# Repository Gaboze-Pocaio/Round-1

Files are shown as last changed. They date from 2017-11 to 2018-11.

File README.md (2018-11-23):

-----

# Where Can I Buy One
> You can purchase an assembled Gaboze Pocaio on [Tindie](https://www.tindie.com/products/thirtytwoteeth/gaboze-pocaio-game-boy-pocket-all-in-one/)

[](https://www.tindie.com/products/thirtytwoteeth/gaboze-pocaio-game-boy-pocket-all-in-one/)

-----

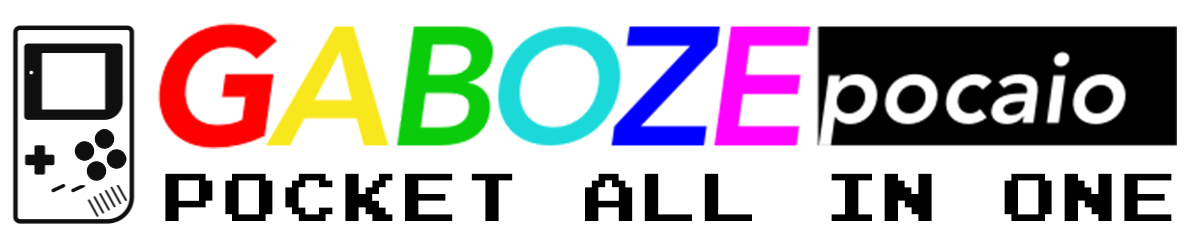
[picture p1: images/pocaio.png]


## Introduction

### Gaboze Pocaio - Pocket All In One
Raspberry Pi Zero based arcade in you pocket, and in your Gameboy Pocket

### Features:

* 2.4" TFT LCD
* Gameboy button layout interface
* Raspberry Pi Zero
* Battery Charger (TP4056 Module)
* Headphone Jack (LM4857)
* Speaker capability (LM4857)

### Platforms:

The boards have been tested with the following platforms:

- [x] [Emulation Station](http://www.emulationstation.org/)
- [x] [Lakka](http://www.lakka.tv/)
### [Lakka for Gaboze Pocaio](https://github.com/32teeth/Lakka-For-Gaboze-Pocaio)
| Out Now | Build Your Own | Out Soon |
|:--:|:--:|:--:|
|  | | |
| *Gaboze Pocaio* | *Gaboze Pocaio Plus* | *Gaboze Pocaio ???* |

- [x] [RetroPie](https://retropie.org.uk/)

## DIY
> Building this yourself? Read the [Wiki](https://github.com/32teeth/GabozePocaio-Round1/wiki/)
* [Preperation](https://github.com/32teeth/GabozePocaio-Round1/wiki/DIY---Preperation)
* [Sound](https://github.com/32teeth/GabozePocaio-Round1/wiki/DIY---Sound-Components)
* [Display](https://github.com/32teeth/GabozePocaio-Round1/wiki/DIY---TFT-Display)

## Details
> The source files have been officially released. Check out the [Files](https://github.com/32teeth/GabozePocaio-Round1/tree/master/eagle/Release) and build away

| Top | Bottom |Money Shot |
| --- | --- |--- |
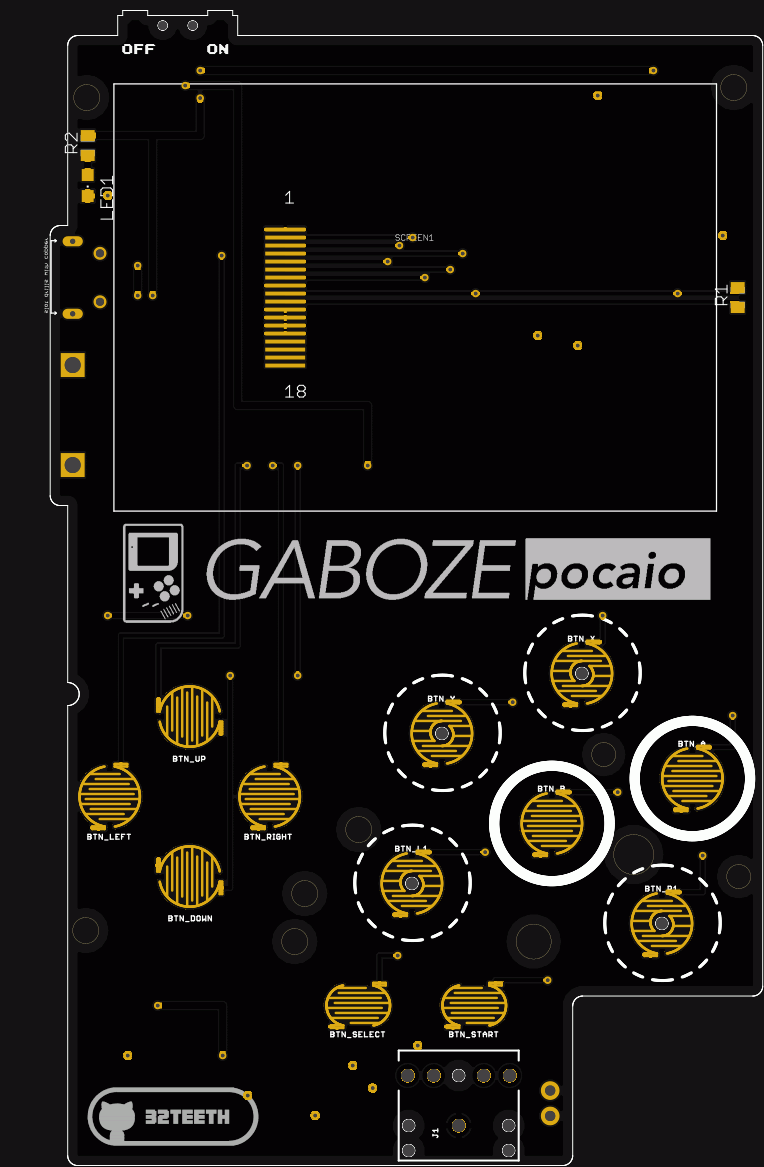
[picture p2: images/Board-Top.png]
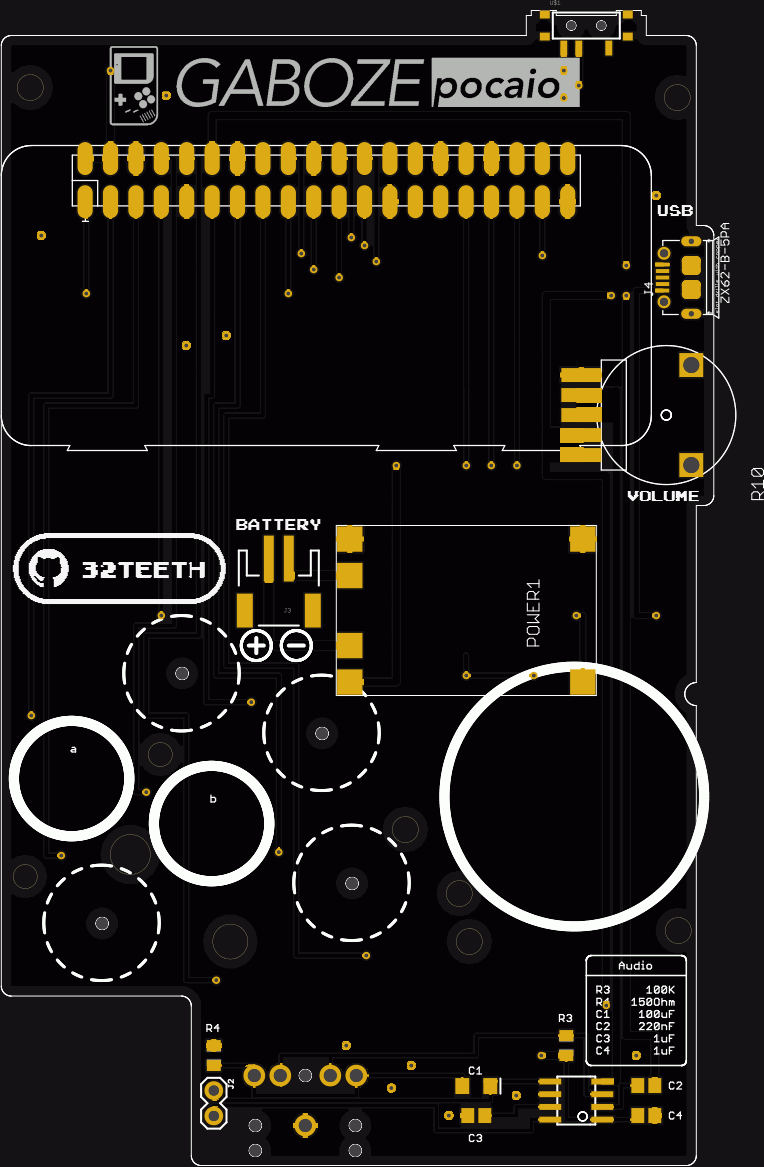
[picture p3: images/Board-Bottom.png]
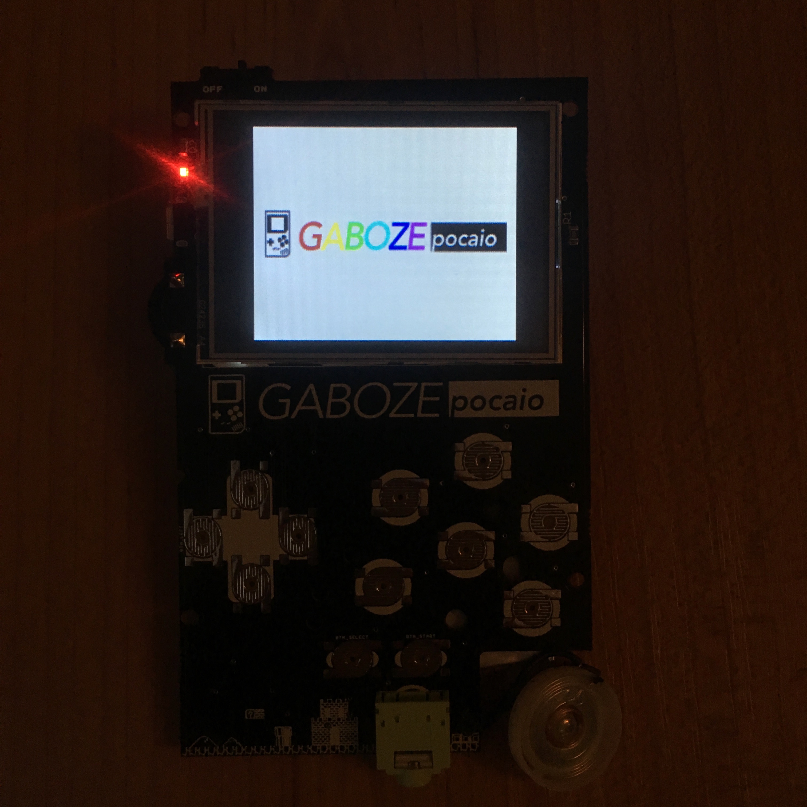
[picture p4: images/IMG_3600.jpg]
|  |  |  |

## Plus Edition
> This is a 2.6" TFT version of the Gaboze Pocaio. The Gerber Files are in the [Plus](https://github.com/32teeth/GabozePocaio-Round1/tree/master/gerber/Plus) folder

| Top | Bottom |Prototype Shot |
| --- | --- |--- |
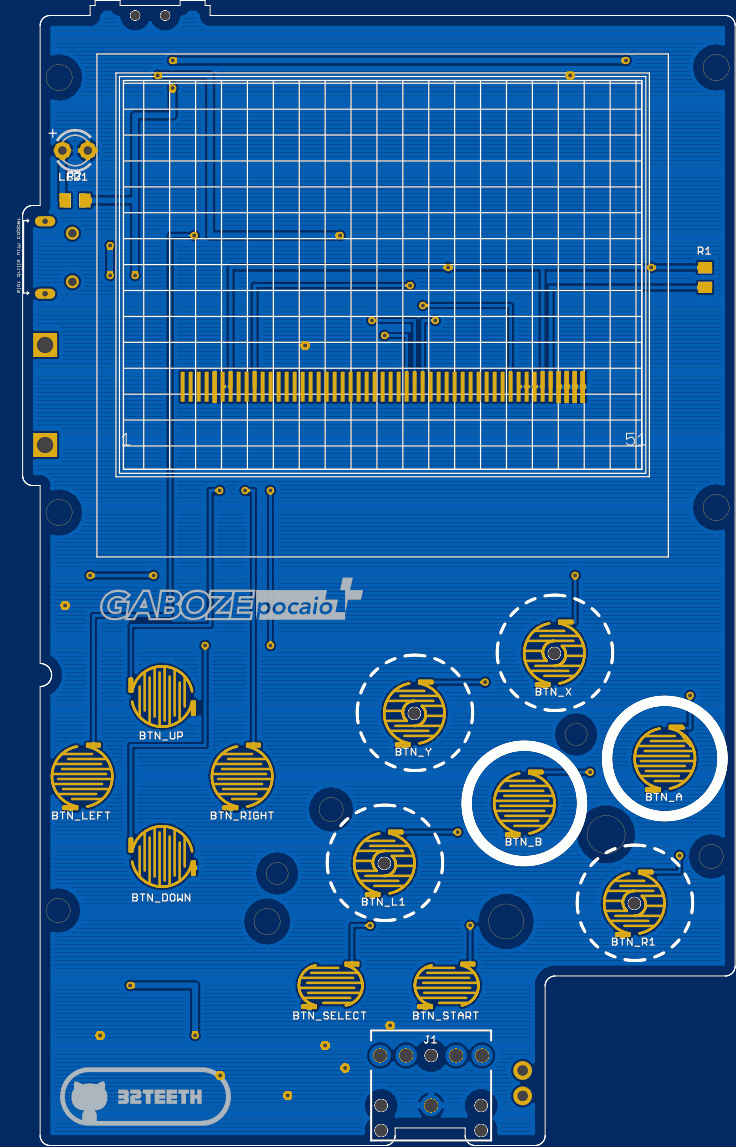
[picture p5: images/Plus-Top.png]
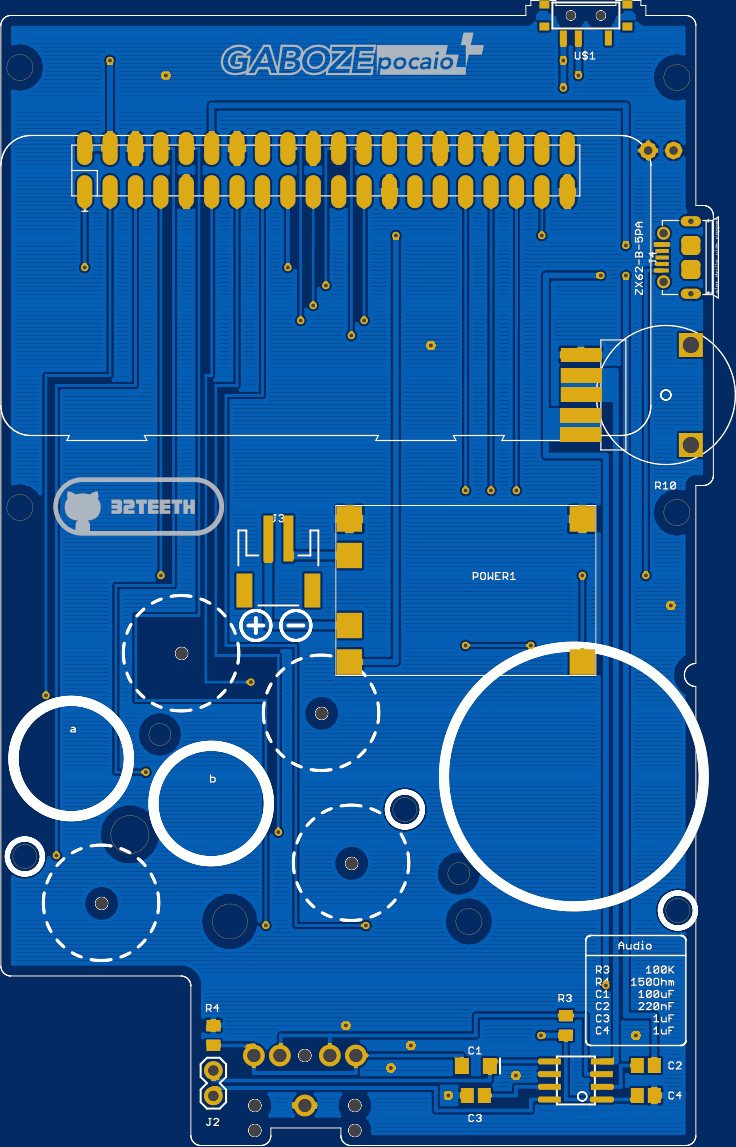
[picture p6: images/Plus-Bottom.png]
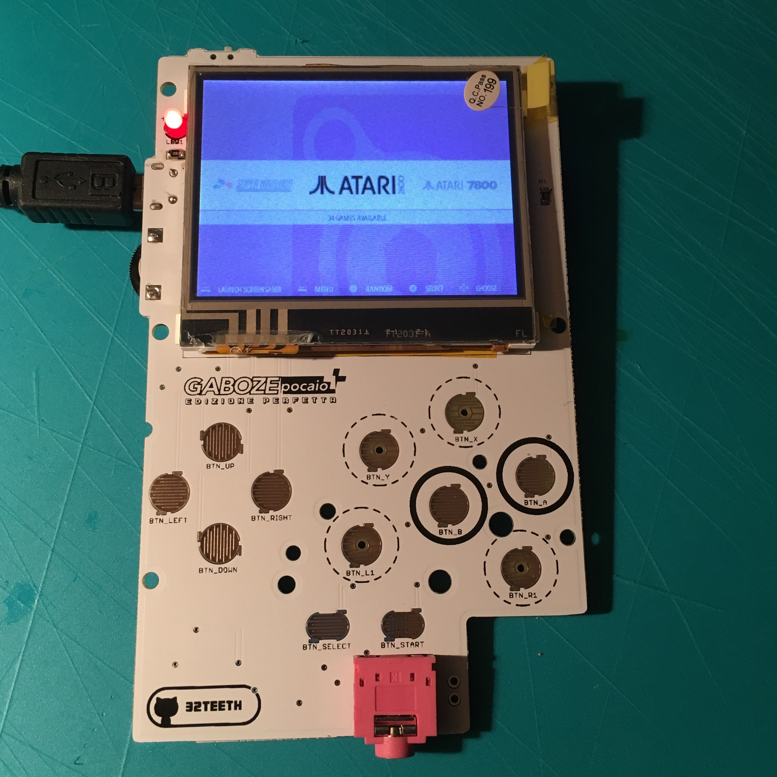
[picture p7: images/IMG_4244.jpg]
|  |  | |

| Overview | Front PCB | Back PCB | Screen | Layout | OSH |
| --- | --- | --- | --- | --- | --- |
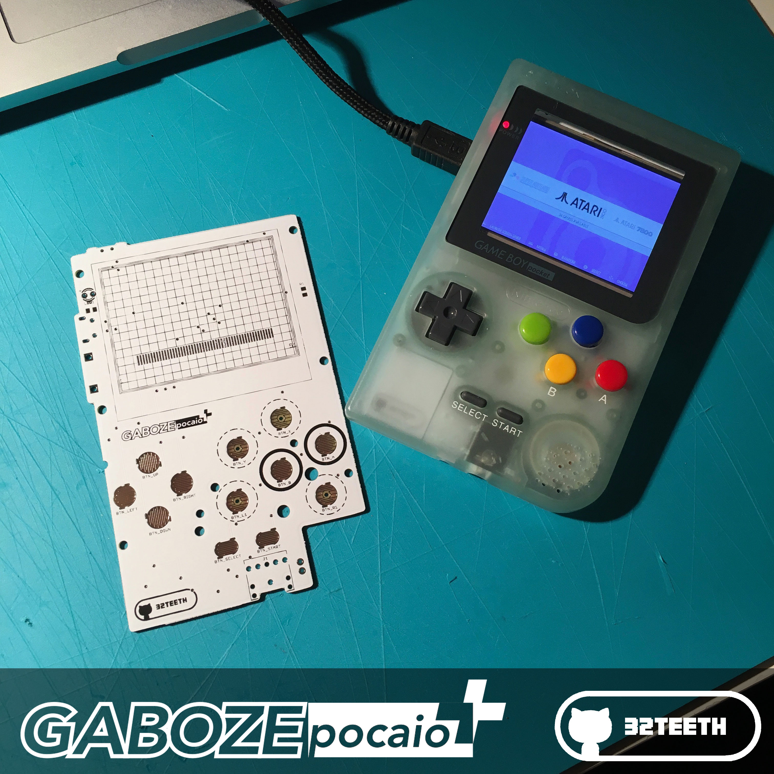
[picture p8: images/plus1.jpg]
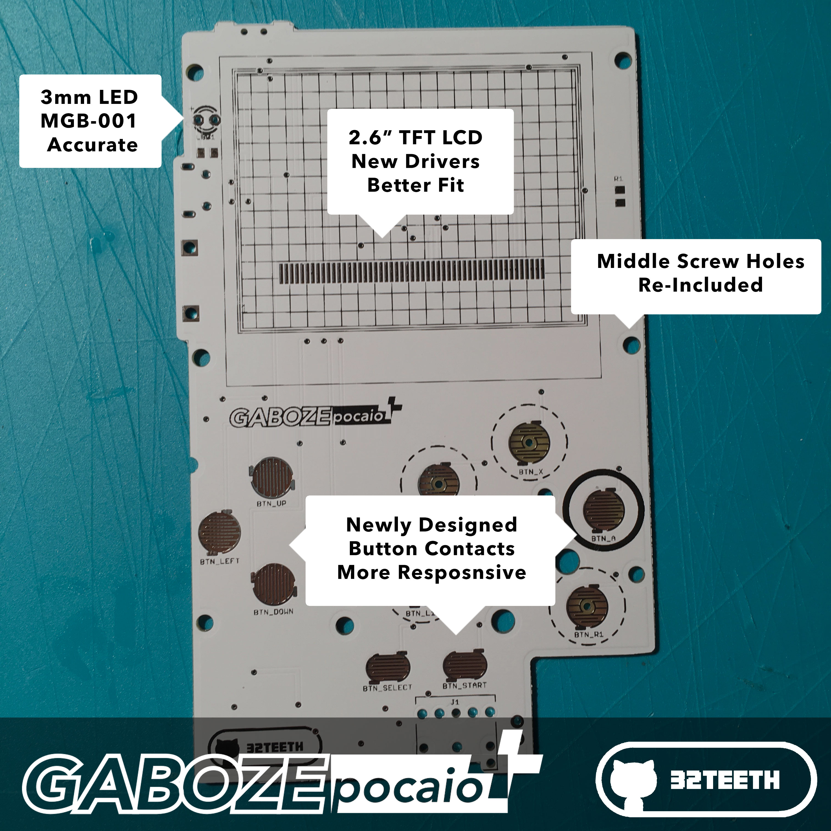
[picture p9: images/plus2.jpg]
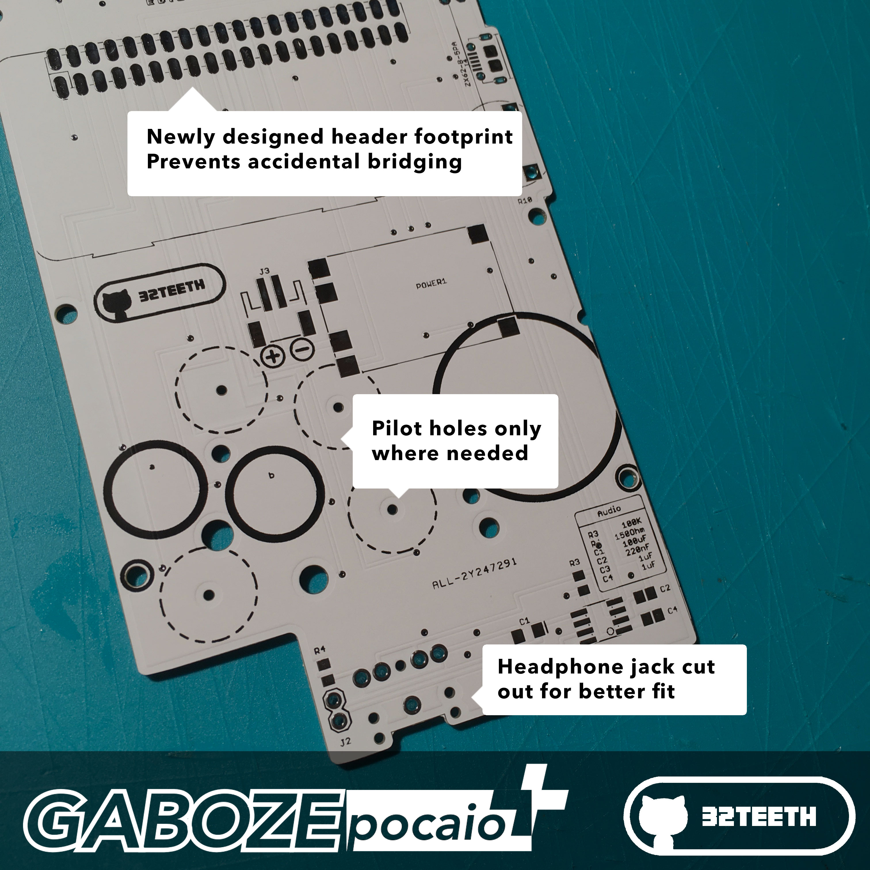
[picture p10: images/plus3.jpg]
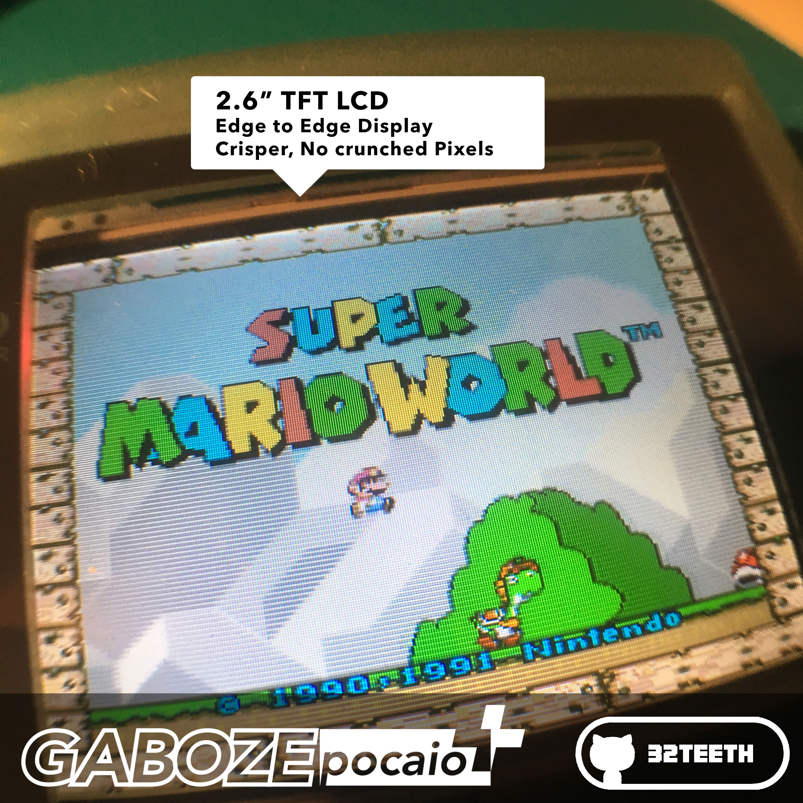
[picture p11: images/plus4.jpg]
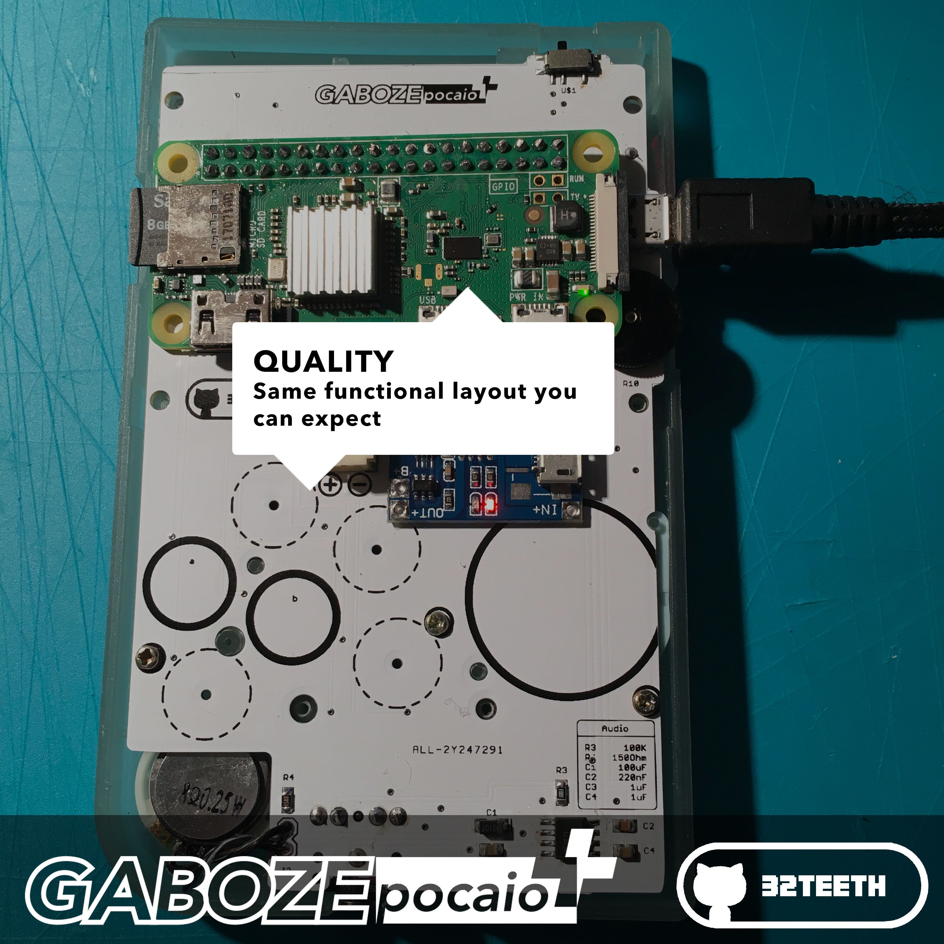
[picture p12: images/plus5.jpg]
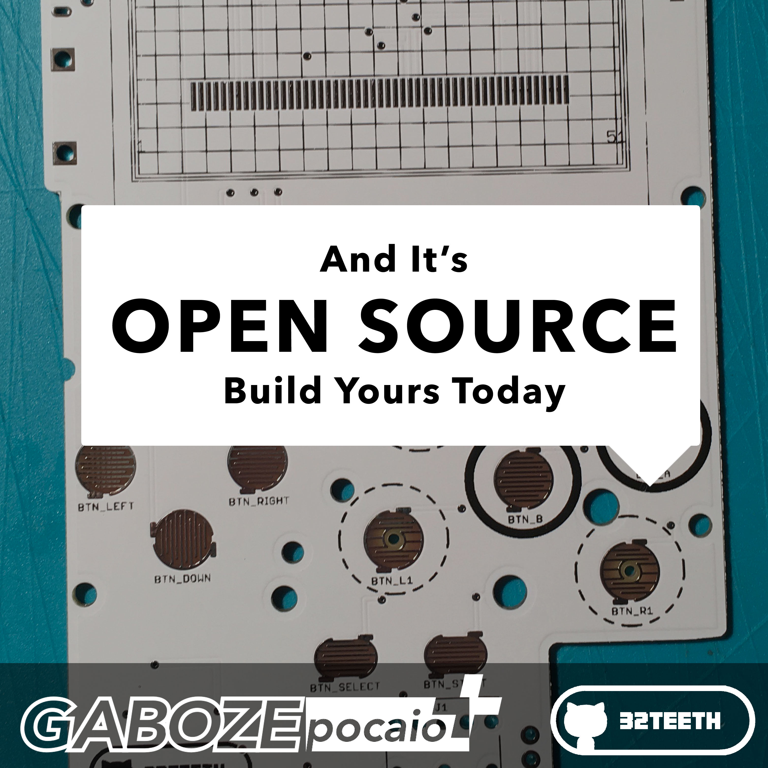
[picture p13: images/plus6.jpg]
|  |  |  |  |  |  |

## Extensions
> So you want to add your own components?

Check out the Gaboze Pocaio Extension Boards
These are available in the [gerber](https://github.com/32teeth/GabozePocaio-Round1/tree/master/gerber) folder

### Auxiliary Board

**Features **

* Power Indicator LED
* Volume Thumbwheel Potentiometer
* Power Input Pins
* Power + Potentiometer Output Pins

|Top|Bottom|Physical|
|-----|-----|-----|
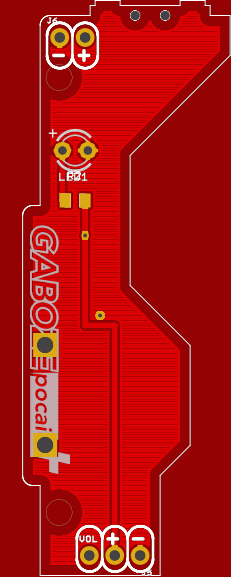
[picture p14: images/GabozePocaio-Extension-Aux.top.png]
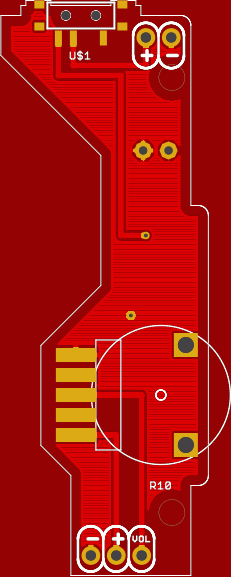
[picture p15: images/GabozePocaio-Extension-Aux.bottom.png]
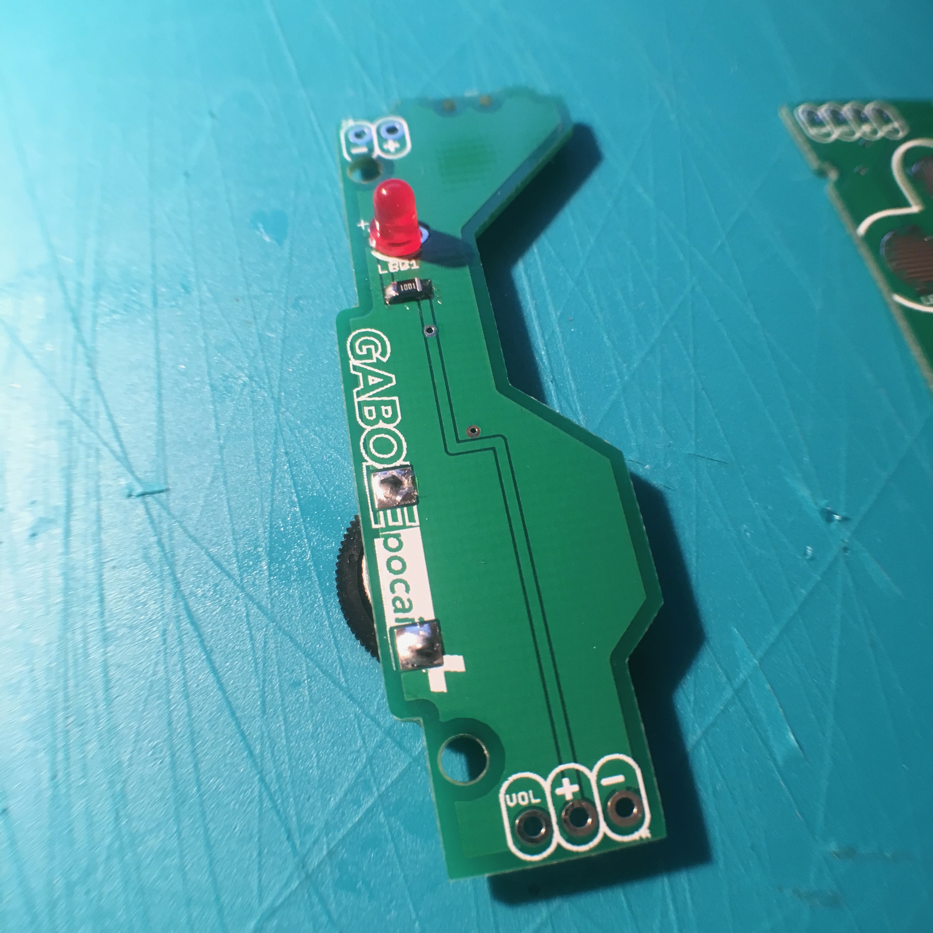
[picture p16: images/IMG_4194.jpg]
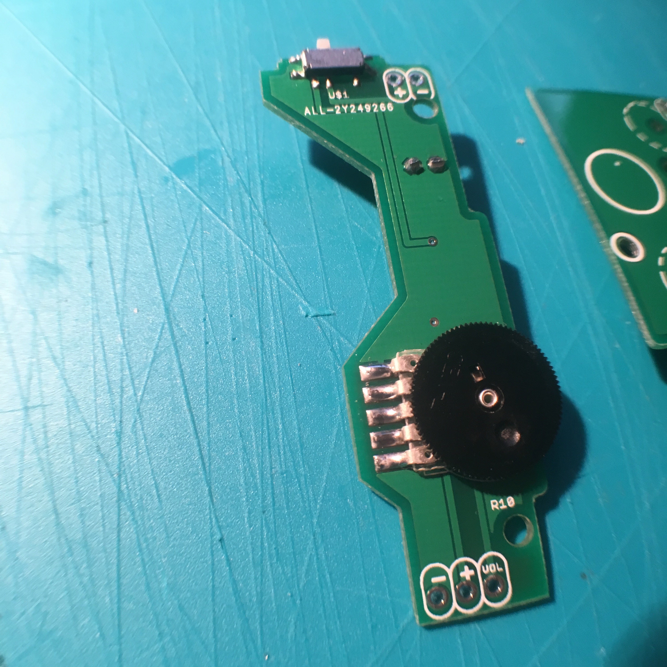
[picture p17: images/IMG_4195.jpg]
||||

[gerber](https://github.com/32teeth/GabozePocaio-Round1/tree/master/gerber/GabozePocaio-Extension-Aux)

### Button + Audio Board

**Features **

* LM4875 Audio Amp
* Headphone Jack
* 4/8 Ohm Speaker Output
* Power + PWM + Potentiometer Input Pins
* Button Pad Output Pins

|Top|Bottom|Physical|
|-----|-----|-----|
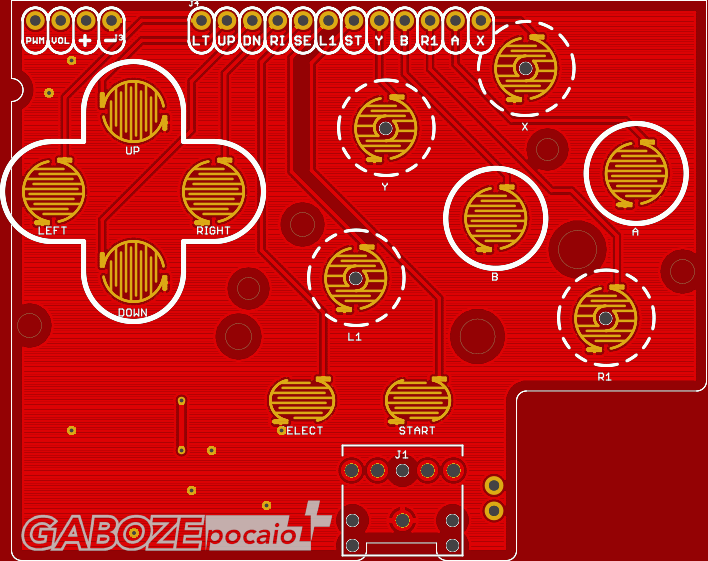
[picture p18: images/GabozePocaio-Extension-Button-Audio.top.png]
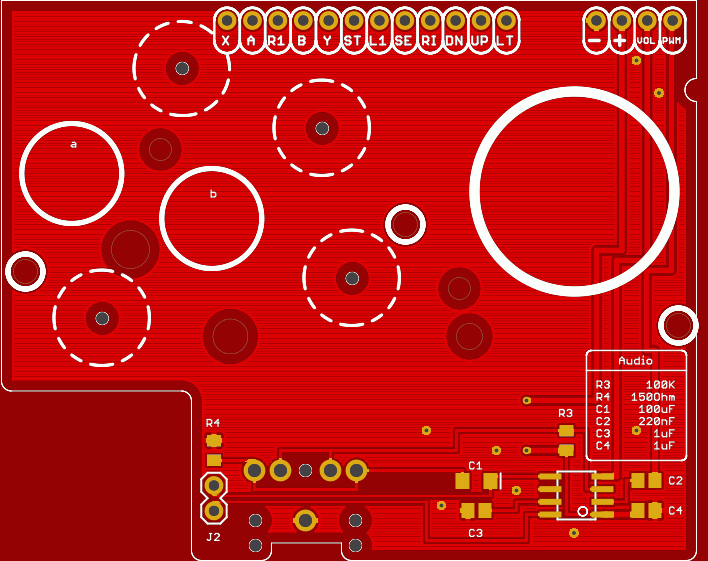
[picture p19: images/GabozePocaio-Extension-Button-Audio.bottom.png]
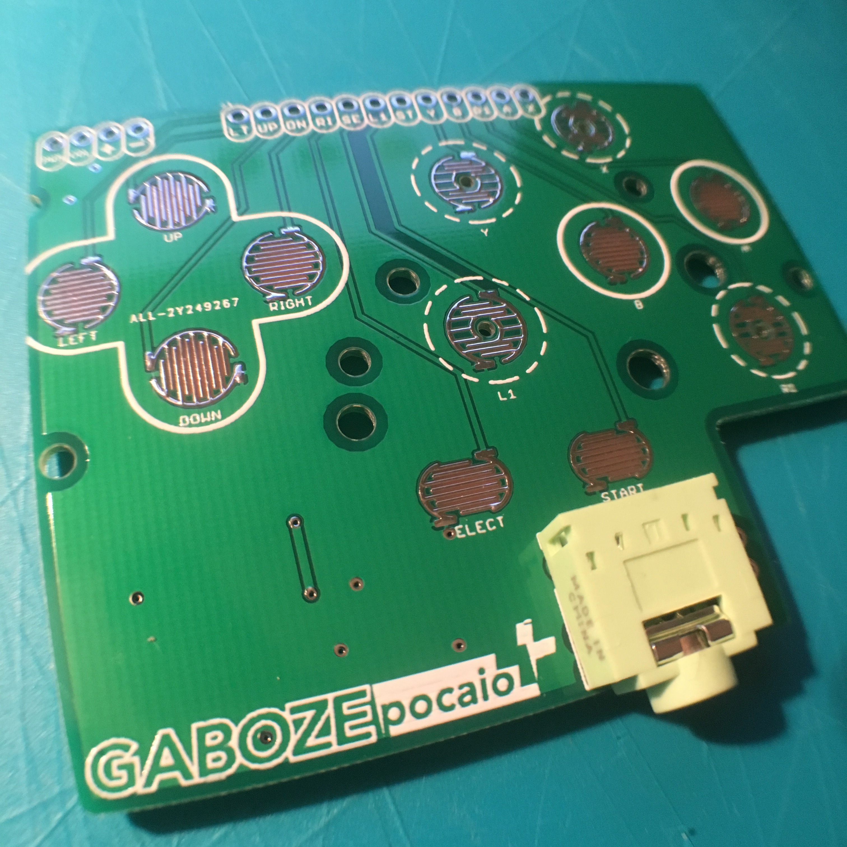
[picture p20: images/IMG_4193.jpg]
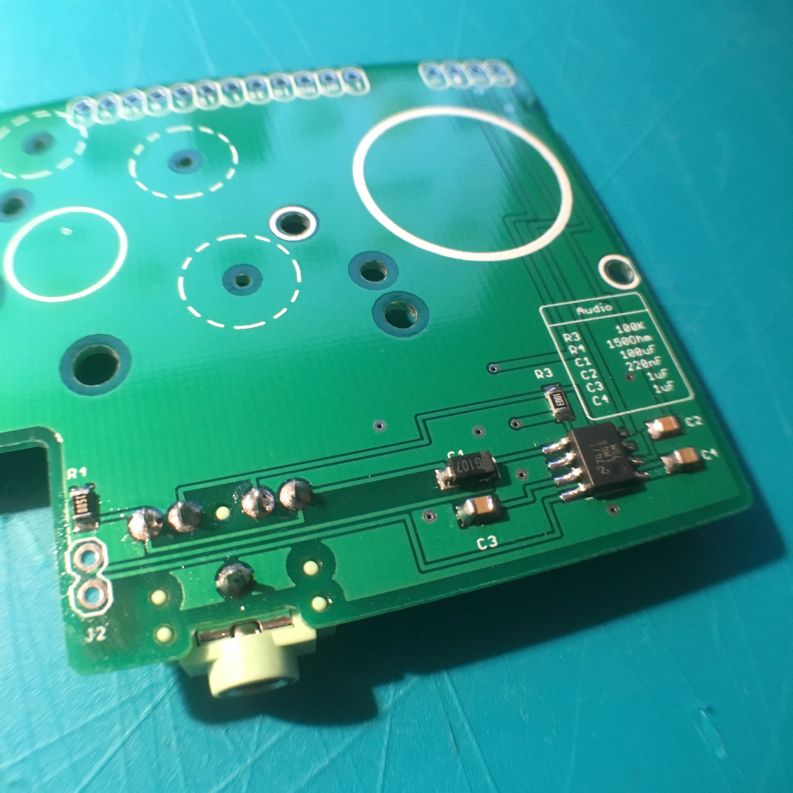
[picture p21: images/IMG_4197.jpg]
||||

[gerber](https://github.com/32teeth/GabozePocaio-Round1/tree/master/gerber/GabozePocaio-Extension-Button-Audio)

## Upgrade to 2.6"
> So you want to upgrade your screen size?

Here's the perfect daughter board solution
These are available in the [gerber](https://github.com/32teeth/GabozePocaio-Round1/tree/master/gerber) folder

**Features **

* Upgrade your display to a 2.6"

**Caviat**

* You WILL NEED to update your Raspberry Pi image with the ILI9342 driver
* If you choose to get a PCB made, make sure it's 0.6mm thickness (optimal is 0.4mm but it will be expensive)

|Top|Bottom|Physical|
|-----|-----|-----|
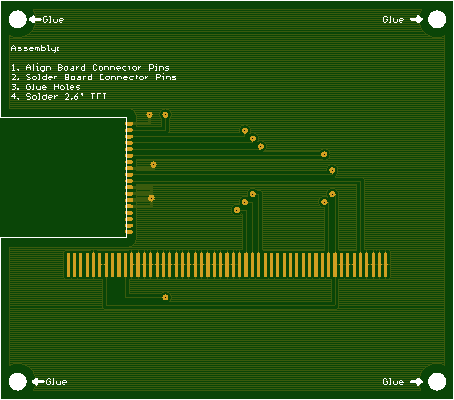
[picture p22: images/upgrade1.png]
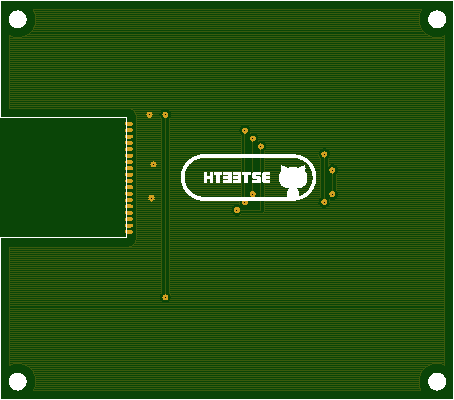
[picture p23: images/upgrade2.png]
|||NO IMAGE|

[source](https://github.com/32teeth/GabozePocaio-Round1/tree/master/eagle/Upgrade)
[gerber](https://github.com/32teeth/GabozePocaio-Round1/tree/master/gerber/Upgrade)

## Cartridge Shell
> So you want to print your own cartridge battery holder

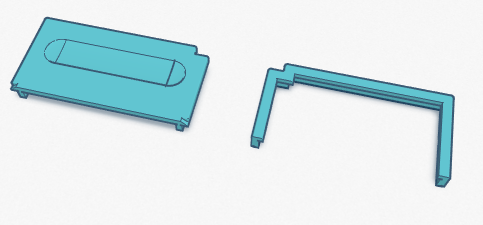
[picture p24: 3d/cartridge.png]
Cartridge Shell
|  |
|:--:|
| *[download stl](https://raw.githubusercontent.com/32teeth/GabozePocaio-Round1/master/3d/cartridge.stl)* |

# Buy me a Coffee
> This is a labor of love, and much time has been put in...  ...i could use a [coffee](https://www.paypal.me/32teeth/1usd) *(donuts are okay too)*

**Thank you for your support**

-----

## Seriously
> READ THE [WIKI](https://github.com/32teeth/GabozePocaio-Round1/wiki/)

-----

### Get In Touch

|    [](https://github.com/32teeth)[](https://www.instagram.com/thirtytwoteeth/)[](https://www.facebook.com/messages/t/32teeth)[](https://twitter.com/eugeneyevhen)[](https://www.youtube.com/user/32teeth/)[](https://ca.linkedin.com/in/32teeth)[](https://www.paypal.me/32teeth/5USD)  |
| ---- |
| Find me on the internet and lets chat |

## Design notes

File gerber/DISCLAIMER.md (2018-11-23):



-----

### Notice
> The gerber files are updated often, and are provided AS IS use
>
> They are provided for free, for educational purposes

* *see [LICENSE](../LICENSE.md) for more detail*

-----

### Combined Images

| Board-Top | Board-Bottom|
|:--:|:--:|
| *Board Top* |*Board Bottom*|

You can check the [EasyEDA Gerber Viewer](https://gerber-viewer.easyeda.com/showcase/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) before manufacturing

### Get In Touch

|    [](https://github.com/32teeth)[](https://www.instagram.com/thirtytwoteeth/)[](https://www.facebook.com/messages/t/32teeth)[](https://twitter.com/eugeneyevhen)[](https://www.youtube.com/user/32teeth/)[](https://ca.linkedin.com/in/32teeth)[](https://www.paypal.me/32teeth/5USD)  |
| ---- |
| Find me on the internet and lets chat |

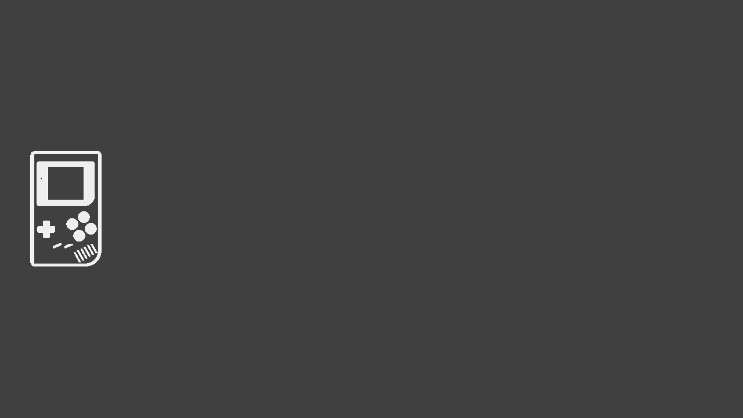
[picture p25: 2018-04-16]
images/animated.gif

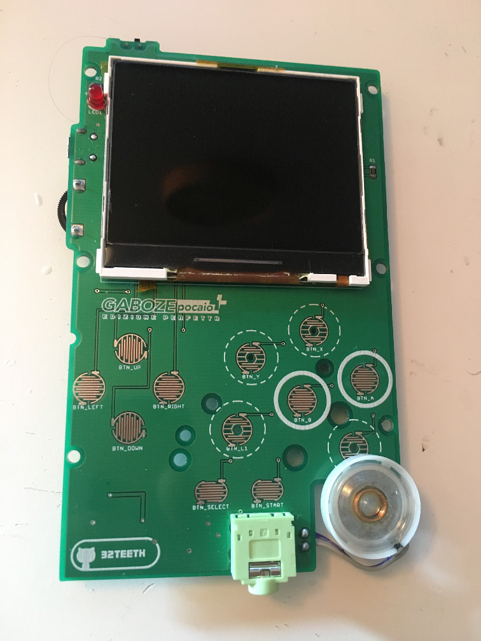
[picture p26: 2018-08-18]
images/plus.jpg

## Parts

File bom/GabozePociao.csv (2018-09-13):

Designator | Description | Manufacturer Part Number | Purchase Link | Quantity
POWER1 | Lithium Battery Charging Board | N/A | https://www.aliexpress.com/item/Free-Shipping-1PCS-5V-Micro-USB-1A-18650-Lithium-Battery-Charging-Board-With-Protection-Charger-Module/32476957358.html | 1
R2 | RES SMD 1.5K OHM 0.1% 1/4W 0805 | ERJ-PB6B1501V | https://www.digikey.ca/product-detail/en/panasonic-electronic-components/ERJ-PB6B1501V/P20612CT-ND/6214867 | 1
R1 | RES 3.9 OHM 1% 1/8W 0805 | RMCF0805FT3R90 | https://www.digikey.ca/product-detail/en/stackpole-electronics-inc/RMCF0805FT3R90/RMCF0805FT3R90CT-ND/2418397 | 1
R3 | RES 100K OHM 5% 1/4W 0805 | RPC0805JT100KCT | https://www.digikey.ca/product-detail/en/stackpole-electronics-inc/RPC0805JT100K/RPC0805JT100KCT-ND/5766007 | 1
C1 | CAP TANT 100UF 4V 20% 1206 | F930G107MAA | https://www.digikey.ca/product-detail/en/avx-corporation/F930G107MAA/478-8134-1-ND/4005954 | 1
R4 | RES 150 OHM 1% 1/4W 0805 | RNCP0805FTD150R | https://www.digikey.ca/product-detail/en/stackpole-electronics-inc/RNCP0805FTD150R/RNCP0805FTD150RCT-ND/2240550 | 1
C3,C4 | CAP CER 1UF 25V X7R 0805 | C0805C105K3RACTU | https://www.digikey.ca/product-detail/en/kemet/C0805C105K3RACTU/399-8004-1-ND/3471727 | 2
C2 | CAP CER 220PF 50V X7R 0805 | C0805C221M5RACTU | https://www.digikey.ca/product-detail/en/kemet/C0805C221M5RACTU/399-8039-1-ND/3471762 | 1
R10 | Replacement Volume Switch for Game boy | N/A | https://www.aliexpress.com/item/Replacement-Volume-Switch-for-Game-boy-for-GBA-GBC-Motherboard-Potentiomete-100pcs-lot/32830491244.html | 1
J3 | CONN HEADER PH SIDE 2POS 2MM SMD | S2B-PH-SM4-TB(LF)(SN | https://www.digikey.ca/product-detail/en/jst-sales-america-inc/S2B-PH-SM4-TB(LF)(SN)/455-1749-1-ND/926846 | 1
2.4TFT-ILI9341 | 2.4 inch SPI Serial LCD | N/A | https://www.aliexpress.com/item/2-4-inch-SPI-Serial-LCD-Without-Touch-ILI9341-4IO-Port-Can-Be-Driven-18-pin/32854563773.html | 1
U1 | IC AMP AUDIO PWR 1W MONO 8SOIC | LM4875MX-NOPB | https://www.digikey.ca/product-detail/en/texas-instruments/LM4875MX-NOPB/296-35282-1-ND/3738990 | 1
PI1 | CONN BERGSTIK II .100 in. DR SMD | 95157-440LF | https://www.digikey.ca/product-detail/en/amphenol-fci/95157-440LF/609-3124-ND/1824561 | 1
LED1 | LED RED CLEAR 0603 SMD | LTST-C191KRKT | https://www.digikey.ca/product-detail/en/lite-on-inc/LTST-C191KRKT/160-1447-1-ND/386836 | 1
X1 | CONN JACK STEREO 3.5MM R/A | CP1-3525NG-GR-ND | https://www.digikey.ca/product-detail/en/cui-inc/SJ1-3525NG-GR/CP1-3525NG-GR-ND/2295990 | 1
U$1 | SWITCH SLIDE SPDT 300MA 4V | MA12RTR | https://www.digikey.ca/product-detail/en/apem-inc/MA12RTR/679-1847-1-ND/1973774 | 1
J2 | SPEAKER 8OHM 250MW TOP PORT 80DB | PSR-20F08S-JQ | https://www.digikey.ca/product-detail/en/mallory-sonalert-products-inc/PSR-20F08S-JQ/458-1122-ND/2071438 | 1
J4 | CONN RCPT USB MICRO B SMD | ZX62D-B-5P8(30) | https://www.digikey.ca/product-detail/en/hirose-electric-co-ltd/ZX62D-B-5P8-30/H125272CT-ND/5994758 | 1

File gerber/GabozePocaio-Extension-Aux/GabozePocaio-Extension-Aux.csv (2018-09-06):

Designator | Description | Manufacturer Part Number | Purchase Link | Quantity
R2 | RES SMD 1.5K OHM 0.1% 1/4W 0805 | ERJ-PB6B1501V | https://www.digikey.ca/product-detail/en/panasonic-electronic-components/ERJ-PB6B1501V/P20612CT-ND/6214867 | 1
R10 | Replacement Volume Switch for Game boy | N/A | https://www.aliexpress.com/item/Replacement-Volume-Switch-for-Game-boy-for-GBA-GBC-Motherboard-Potentiomete-100pcs-lot/32830491244.html
LED1 | LED3MM RED (LED) | https://www.digikey.ca/product-detail/en/kingbright/WP710A10ID5V/754-1721-ND/3084187 | 1
U$1 | SWITCH SLIDE SPDT 300MA 4V | MA12RTR | https://www.digikey.ca/product-detail/en/apem-inc/MA12RTR/679-1847-1-ND/1973774 | 1
J5,J6 | NOT POPULATE | NOT POPULATED | 2

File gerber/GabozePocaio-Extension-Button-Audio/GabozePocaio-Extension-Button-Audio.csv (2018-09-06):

Designator | Description | Manufacturer Part Number | Purchase Link | Quantity
U1 | IC AMP AUDIO PWR 1W MONO 8SOIC | LM4875MX-NOPB | https://www.digikey.ca/product-detail/en/texas-instruments/LM4875MX-NOPB/296-35282-1-ND/3738990 | 1
R3 | RES 100K OHM 5% 1/4W 0805 | RPC0805JT100KCT | https://www.digikey.ca/product-detail/en/stackpole-electronics-inc/RPC0805JT100K/RPC0805JT100KCT-ND/5766007 | 1
R4 | RES 150 OHM 1% 1/4W 0805 | RNCP0805FTD150R | https://www.digikey.ca/product-detail/en/stackpole-electronics-inc/RNCP0805FTD150R/RNCP0805FTD150RCT-ND/2240550 | 1
C1 | CAP TANT 100UF 4V 20% 1206 | F930G107MAA | https://www.digikey.ca/product-detail/en/avx-corporation/F930G107MAA/478-8134-1-ND/4005954 | 1
C3,C4 | CAP CER 1UF 25V X7R 0805 | C0805C105K3RACTU | https://www.digikey.ca/product-detail/en/kemet/C0805C105K3RACTU/399-8004-1-ND/3471727 | 2
C2 | CAP CER 220PF 50V X7R 0805 | C0805C221M5RACTU | https://www.digikey.ca/product-detail/en/kemet/C0805C221M5RACTU/399-8039-1-ND/3471762 | 1
J1 | CONN JACK STEREO 3.5MM R/A | CP1-3525NG-PI-ND | https://www.digikey.ca/product-detail/en/cui-inc/SJ1-3525NG-PI/CP1-3525NG-PI-ND/2295991 | 1
J2 | SPEAKER 8OHM 250MW TOP PORT 80DB | PSR-20F08S-JQ | https://www.digikey.ca/product-detail/en/mallory-sonalert-products-inc/PSR-20F08S-JQ/458-1122-ND/2071438 | 1
J3,J4 | NOT POPULATE | NOT POPULATED | 2

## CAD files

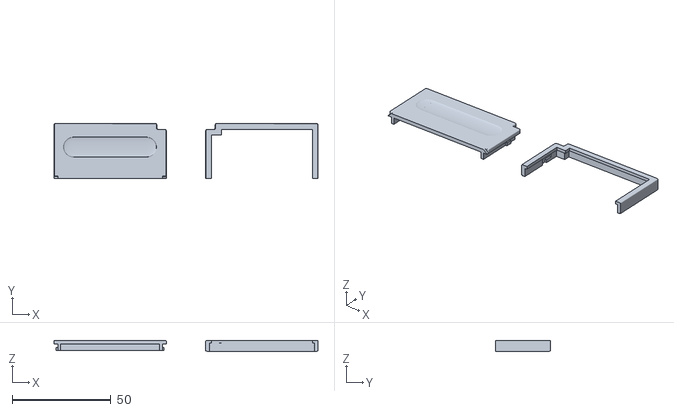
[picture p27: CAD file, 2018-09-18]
3d/cartridge.stl
133.7 x 28.0 x 5.70

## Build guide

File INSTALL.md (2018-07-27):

# Gaboze Pocaio Installation

> This document is intended for a somewhat advanced user base, but we have made it simple enough to follow along for anyone

- [Gaboze Pocaio Installation](#gaboze-pocaio-installation)
    + [Prerequisites](#prerequisites)
  * [Step 1](#step-1)
    + [WiFi](#wifi)
      - [Optional](#optional)
  * [Step 2](#step-2)
    + [TFT Device](#tft-device)
  * [Step 3](#step-3)
    + [Automate the above on startup](#automate-the-above-on-startup)
    + [Create a configuration file for the TFT LCD Module](#create-a-configuration-file-for-the-tft-lcd-module)
    + [Installing the Framebuffer Copy tool](#installing-the-framebuffer-copy-tool)
    + [Add Framebuffer Copy to our boot sequence](#add-framebuffer-copy-to-our-boot-sequence)
  * [Step 4](#step-4)
    + [General Config](#general-config)
  * [Step 5](#step-5)
    + [Install RetroGame](#install-retrogame)
      - [Don't reboot just yet](#don-t-reboot-just-yet)
  * [Step 6](#step-6)
    + [RetroGame Configuration](#retrogame-configuration)
    + [EmulationStation Input Configuration](#emulationstation-input-configuration)
  * [Step 7](#step-7)
  * [Step 8](#step-8)

### Prerequisites

1. Fresh RetroPie install mounted on an SD Card
2. Raspberry Pi Zero *(preferably WiFi edition)*
3. Keyboard
4. OTG USB Cable (to plug in a USB A type keyboard)
5. Mini HDMI (you know, to see things on a screen)

## Step 1

> Setup Raspberry Pi requirements

With your Keyboard and HDMI cable plugged in, go ahead and turn on your Raspberry Pi Zero
Allow it to go through the boot requirements (RetroPie will reboot once on it's own)

Once the Raspberry Pi boots into RetroPie, it will start EmulationStation automatically.

You will see a screen telling you to either set up a controller or press F4 to exit.

- Press F4 to exit to terminal
- Run the Rapsberry Pi configuration program

```shell
sudo raspi-config
```

In the Interfaceing Options menu, you will need to

1. Enable SSH
2. Enable SPI

In the Advance Options menu, you will need to

1. Expand Filesystem
2. Disable Overscan

Once these are complete, you will be asked to reboot you Raspbery Pi.
Do so.

### WiFi

Once the Raspberry Pi reboots into EmulationStation, use your keyboard and navigate to RetroPie configuration

Select WiFi and enter your SSID/PSK information as necessary

Once you have connected to your WiFi network, you can go back to your laptop and continue via SSH from there

#### Optional

Should you choose to work completely from terminal, hit F4 from the EmulationStation menu to get to terminal

```shell
sudo iwlist wlan0 scan
sudo nano /etc/wpa_supplicant/wpa_supplicant.conf
```

```shell
network={
  ssid="your ssid"
  psk="your password"
}
```

```shell
sudo systemctl daemon-reload
ifconfig wlan0
```

If you have done your WiFi correctly from here you can use SSH

```
ssh pi@[ip address]
```

## Step 2

> We will now be connecting the 2.8" ILI9341 TFT LCD module, so you can set your other keyboard aside for now

From you computer *(not the Raspberry Pi)*

### TFT Device

Enter the following to add a Loadable Kernel Module for the TFT Device

*TFT LCD footprint on right*
```shell
sudo modprobe fbtft_device custom name=fb_ili9341 gpios=reset:25,dc:24 speed=60000000 fps=60 bgr=1 rotate=270
```

*TFT LCD footprint on left*
```shell
sudo modprobe fbtft_device custom name=fb_ili9341 gpios=reset:25,dc:24 speed=60000000 fps=60 bgr=1 rotate=90
```

Confirm the module has been loaded

```shell
dmesg | tail
```

See the TFT LCD module details

```shell
fbset -fb /dev/fb1
```

Lets test that we can show 'stuff' on the TFT LCD module (this will simply add static noise)

```shell
cat /dev/urandom > /dev/fb1
```

Map the console to the TFT LCD Module
*you should now see a scaled terminal window on the TFT*

```shell
con2fbmap 1 1
```

Should you ever need to stop the mapping, reverse the command

```shell
# switch tft to hdmi
con2fbmap 1 0
```

*Note:* if you need to remove the module, simply

```shell
sudo modprobe -r fbtft_device
```

## Step 3

### Automate the above on startup

Open the modules file

```shell
sudo nano /etc/modules
```

Add these lines to the bottom

```shell
spi-bcm2835
fbtft_device
```

*Hit 'CTRL+X' and 'Y' to confirm the save*

### Create a configuration file for the TFT LCD Module

This will create an empty file named fbtft.conf

```shell
sudo nano /etc/modprobe.d/fbtft.conf
```

Add this line to the empty file

*TFT LCD footprint on right*
```shell
options fbtft_device custom name=fb_ili9341 gpios=reset:25,dc:24 speed=80000000 fps=60 bgr=1 rotate=270 custom=1
```

*TFT LCD footprint on left*
```shell
options fbtft_device custom name=fb_ili9341 gpios=reset:25,dc:24 speed=80000000 fps=60 bgr=1 rotate=90 custom=1
```

*Hit 'CTRL+X' and 'Y' to confirm the save*

### Installing the Framebuffer Copy tool

The following lines will download and install the Frambuffer Copy tool in a folder in the root directory

```shell
cd
sudo apt-get install cmake
git clone https://github.com/tasanakorn/rpi-fbcp fbcp
cd fbcp/
mkdir build
cd build/
cmake ..
make
sudo install fbcp /usr/local/bin/fbcp
fbcp
```

*Hit CTRL+C to exit 'fbcp'*

### Add Framebuffer Copy to our boot sequence

In order to have a command or program run when the Pi boots we will edit the 'rc.local' file

```shell
sudo nano /etc/rc.local
```

Add the following **just before** the ```exit 0``` line

```shell
fbcp&
```

*Hit 'CTRL+X' and 'Y' to confirm the save*

Your file *(if you have no other commands running)* will look something like this

```shell
### replace with this
_IP=$(hostname -I) || true
if [ "$_IP" ]; then
  printf "My IP address is %s\n" "$_IP"
fi

fbcp&

exit 0
```

## Step 4

### General Config

Enable PWM sound, lcd rotation and overlay, open cmdline.txt

```shell
sudo nano /boot/config.txt
```

add this to the bottom
```shell
# PWM audio
dtoverlay=pwm,pin=18,func=2

# Rotate screen for Gameboy Pocket Zero
# 2 = TFT LCD on right, 0 = TFT LCD on left
lcd_rotate=2
```

now go find the line with ```disable_overscan``` and uncomment and add 0 as the value
```shell
disable_overscan=0
overscan_scale=1
```

below that you will see a few commented out lines for overscan. change them as such

*TFT LCD footprint on right*
```shell
overscan_left=15
overscan_right=-30
overscan_top=-30
overscan_bottom=-30
```

*TFT LCD footprint on left* (you may need to play with the numbers a bit)
```shell
overscan_left=-30
overscan_right=15
overscan_top=-30
overscan_bottom=-30
```

If you are lazy, the whole config.txt file is in the *boot* folder of this repository. Simply replace the whole thing.

Reboot.

## Step 5

> Now we are ready to configure the GPIO on the Raspberry Pi as a controller

### Install RetroGame

```shell
cd
curl -O https://raw.githubusercontent.com/adafruit/Raspberry-Pi-Installer-Scripts/master/retrogame.sh
sudo bash retrogame.sh
```

When you run the retrogame.sh file, you will be presented with a menu.

Select the **PiGRRL 2 Controls** option, and the program will continue to install some modules.

Once complete, you will be asked if you want to reboot.

#### Don't reboot just yet

## Step 6

> You will now be assigning keyboard inputs to action buttons of the controller (GPIO pins on the Raspberry Pi)

### RetroGame Configuration

Edit the RetroGame configuration file

```shell
sudo nano /boot/retrogame.cfg
```

You can replace the entire file with the following

- **pro tip**:Hit CTRL+K on you keyboard to delete lines*

```shell
# Here's a pin configuration for the PiGRRL 2 project:
LEFT            26  # Joypad left
RIGHT           13  # Joypad right
UP              19  # Joypad up
DOWN             6  # Joypad down
LEFTCTRL        14  # 'A' button
LEFTALT         27  # 'B' button
Z                4  # 'X' button
X               17  # 'Y' button
RIGHTSHIFT      22  # 'Select' button
ENTER           15  # 'Start' button
A                2  # Left shoulder button
S                3  # Right shoulder button
ESC             22 15  # Exit ROM; PiTFT Button 1
```

*Hit 'CTRL+X' and 'Y' to confirm the save*

### EmulationStation Input Configuration

> This is really just a visual check to ensure your file looks as below

Open the EmulationStation Input configuration file

```shell
sudo nano ~/.emulationstation/es_input.cfg
```

Ensure that your file's content are **exactly** as below

```xml
<?xml version="1.0"?>
<inputList>
  <inputAction type="onfinish">
    <command>/opt/retropie/supplementary/emulationstation/scripts/inputconfiguration.sh</command>
  </inputAction>
  <inputConfig type="keyboard" deviceName="Keyboard" deviceGUID="-1">
    <input name="pageup" type="key" id="1073742050" value="1"/>
    <input name="start" type="key" id="13" value="1"/>
    <input name="up" type="key" id="1073741906" value="1"/>
    <input name="a" type="key" id="97" value="1"/>
    <input name="b" type="key" id="1073742048" value="1"/>
    <input name="down" type="key" id="1073741905" value="1"/>
    <input name="pagedown" type="key" id="115" value="1"/>
    <input name="right" type="key" id="1073741903" value="1"/>
    <input name="x" type="key" id="122" value="1"/>
    <input name="select" type="key" id="1073742053" value="1"/>
    <input name="y" type="key" id="120" value="1"/>
    <input name="left" type="key" id="1073741904" value="1"/>
  </inputConfig>
</inputList>
```

If all is good as above, hit CTRL+X to exit the editor and

## Step 7
> Command line to show boot message (optional)

Default cmdline.txt should be as follows

```shell
dwc_otg.lpm_enable=0 console=serial0,115200 console=tty1 root=PARTUUID=3d24ca30-02 rootfstype=ext4 elevator=deadline fsck.repair=yes rootwait loglevel=3 consoleblank=0 plymouth.enable=0
```

If you want to see a boot message instead of a black screen.

```shell
sudo nano /boot/cmdline.txt
```

Replace everything with this

```shell
dwc_otg.lpm_enable=0 console=tty1 console=ttyAMA0,115200 root=/dev/mmcblk0p2 rootfstype=ext4 elevator=deadline rootwait fbcon=map:10 fbcon=font:6x12 logo.nologo
```

**Reboot**

```shell
sudo reboot now
```

RetroPie will reboot and start EmulationStation *(all on the tiny screen)*

Once EmulationStation is up, you will again see the 'No Device Configured' screen...  ...***Don't Panic***

With your keyboard plugged in, press and hold 'Enter' until the Controller Configuration shows up on the screen

Hit your keys on your keyboard as mapped above, skip the analog sticks

## Step 8

> This one is all on you

We **DO NOT** provide any system or game *'roms'*, for that you will need Google.

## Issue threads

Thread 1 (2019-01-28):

White screen issue

mswartz, 2019-01-28:
Hi there, I assembled my Round 1 board over the weekend and am having trouble getting past the white screen on the embedded display. I followed your guide and tested the board, reflowed the battery board things, but still no luck. If I plug in an hdmi cable and monitor it works fine, just can't get the display on the board to work. What do you reckon?

mswartz, 2019-02-05:
Doing some more testing, it appears the buttons on the board don't work either. If I plug in a keyboard and an hdmi monitor, it boots into retropie and regognizes my usb keyboard. But it does not recognize button presses or do anything on the screen but display a white screen. Is the board faulty? The Pi and software seem fine.

negativ72rus, 2019-03-13:
Hello!
I ran into a similar problem, what could be wrong?

mswartz, 2019-03-18:
No idea. I had 2 that were having the exact same problem. He replied and sent me a link to his official firmware, which fixed one of them, but the other is still WSODed. Haven't heard back from him about why that might be. @32teeth: any ideas?

negativ72rus, 2019-04-15:
> No idea. I had 2 that were having the exact same problem. He replied and sent me a link to his official firmware, which fixed one of them, but the other is still WSODed. Haven't heard back from him about why that might be. @32teeth: any ideas?

@mswartz Can you share a link to the firmware? from the repository of the first round, they missed where they went.

32teeth, 2019-04-15:
[Downloads Site](http://gameboy.32teeth.org/)

Closed 2019-04-15.

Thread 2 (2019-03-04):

Board with RPI doesn't fit in case

lukesky333, 2019-03-04:
I've the problem that the board including the RPI doesn't fit into the case.

Do you have any idea howto fix it? What are your recommendations for soldering the RPI on the board?

32teeth, 2019-03-11:
Please provide image

32teeth, 2019-03-12:
Closing for lack of response.
Possible fake user.

Closed 2019-03-12.

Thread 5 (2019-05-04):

no clear sound

negativ72rus, 2019-05-04:
there are other sounds like crackles from the speaker
What can be wrong?

ltpitt, 2019-05-15:
Try lowering the gain from alsamixer

negativ72rus, 2019-05-15:
The problem was the power supply. I powered the circuit from 18650, my screen blinked and there were interferences in the sound. When I put a flat lithium polymer battery, everything returned to normal.

Closed 2019-05-15.

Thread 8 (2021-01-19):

C2 wrong capacitance

retrotails, 2021-01-19:
same as the issue for the round 2, the "DIY Preperation" page in the wiki and it's digikey carts list a 220pF capacitor (C2) instead of the correct 220**nF**. the round 1 silkscreen actually has the correct unit listed from the beginning.
https://github.com/Gaboze-Pocaio/Round-2/issues/12
https://github.com/Gaboze-Pocaio/Round-1/wiki/DIY---Preperation

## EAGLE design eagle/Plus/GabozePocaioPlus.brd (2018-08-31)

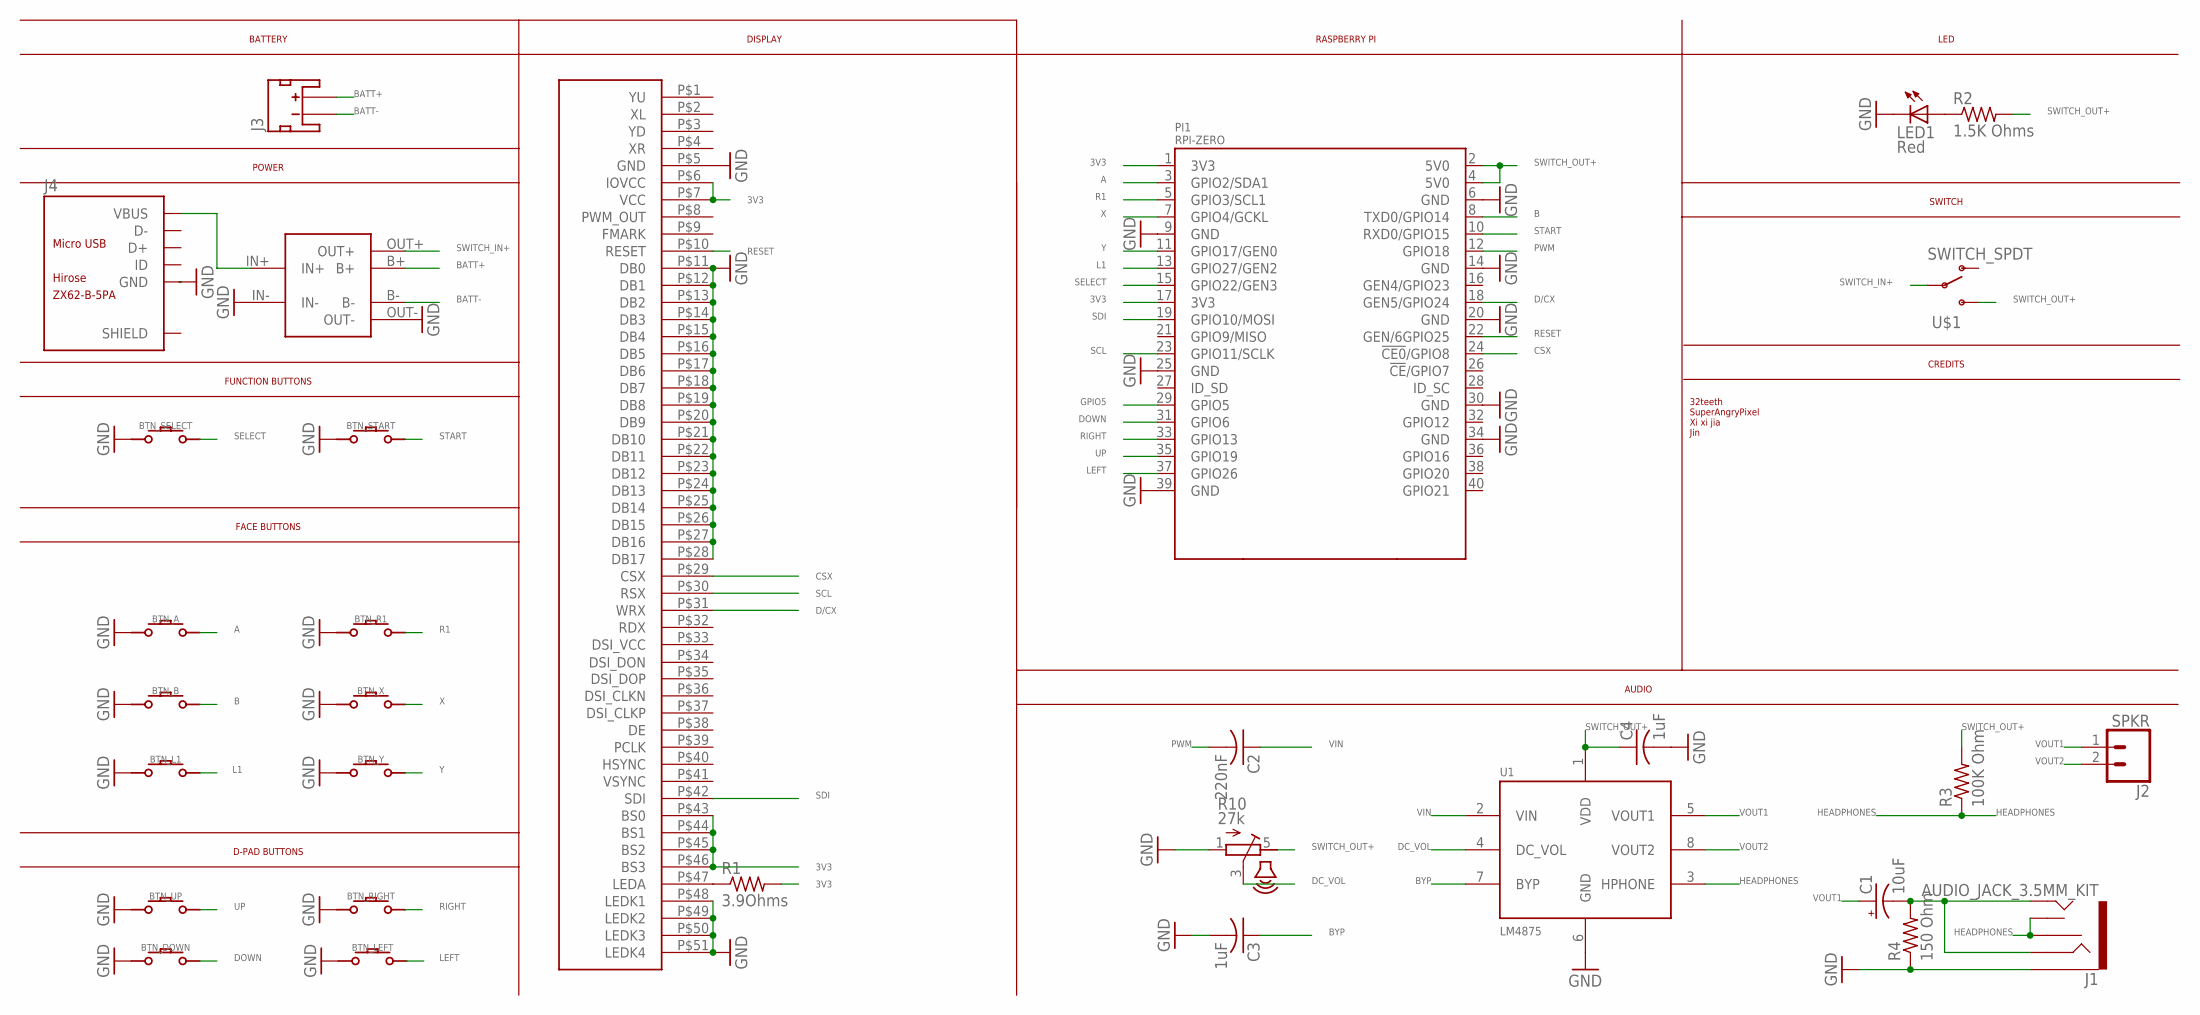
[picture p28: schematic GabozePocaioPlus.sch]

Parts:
BTN_A: CONDUCTIVE_BUTTON
BTN_B: CONDUCTIVE_BUTTON
BTN_DOWN: CONDUCTIVE_BUTTON
BTN_L1: CONDUCTIVE_BUTTON_DRILL
BTN_LEFT: CONDUCTIVE_BUTTON
BTN_R1: CONDUCTIVE_BUTTON_DRILL
BTN_RIGHT: CONDUCTIVE_BUTTON
BTN_SELECT: CONDUCTIVE_BUTTON_STARTSELECT
BTN_START: CONDUCTIVE_BUTTON_STARTSELECT
BTN_UP: CONDUCTIVE_BUTTON
BTN_X: CONDUCTIVE_BUTTON_DRILL
BTN_Y: CONDUCTIVE_BUTTON_DRILL
C1: 10uF; EIA3216
C2: 220nF; C0805
C3, C4: 1uF; C0805
J1: AUDIO_JACK_3.5MM_KIT; AUDIO-JACK-KIT
J2: SPKR; 1X02
J3: Batt Conn; JST-2-SMD
J4: ZX62-B-5PA; MICRO-USB5+6P-SMD-0.65-AB
LED1: Red; LED3MM
PI1: RPI-ZERO
POWER1: 03962A
R1: 3.9Ohms; R0805
R2: 1.5K Ohms; R0805
R3: 100K Ohm; R0805
R4: 150 Ohm; R0805
R10: 27k; VOLUME
U1: LM4875; SOIC8
U$1: SWITCH_SPDT; KPS-1290
U$2: TFT-DISPLAY-2.6-51PIN

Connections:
3V3: PI1.1 (3V3), PI1.17 (3V3), R1.2, U$2.P$6 (IOVCC), U$2.P$7 (VCC), U$2.P$43 (BS0), U$2.P$44 (BS1), U$2.P$45 (BS2), U$2.P$46 (BS3)
A: BTN_A.P$ACTIVE, PI1.3 (GPIO2/SDA1)
B: BTN_B.P$ACTIVE, PI1.8 (TXD0/GPIO14)
BATT+: J3.2 (+), POWER1.B+
BATT-: J3.1 (-), POWER1.B-
BYP: C3.1, U1.7 (BYP)
CSX: PI1.24 (!CE0!/GPIO8), U$2.P$29 (CSX)
D/CX: PI1.18 (GEN5/GPIO24), U$2.P$31 (WRX)
DC_VOL: R10.3 (S), U1.4 (DC_VOL)
DOWN: BTN_DOWN.P$ACTIVE, PI1.31 (GPIO6)
GND: BTN_A.P$GND, BTN_B.P$GND, BTN_DOWN.P$GND, BTN_L1.P$GND, BTN_LEFT.P$GND, BTN_R1.P$GND, BTN_RIGHT.P$GND, BTN_SELECT.P$GND, BTN_START.P$GND, BTN_UP.P$GND, BTN_X.P$GND, BTN_Y.P$GND, C3.2, C4.2, J1.SLEEVE, J4.5 (GND), LED1.K (C), PI1.6 (GND), PI1.9 (GND), PI1.14 (GND), PI1.20 (GND), PI1.25 (GND), PI1.30 (GND), PI1.34 (GND), PI1.39 (GND), POWER1.IN-, POWER1.OUT-, R4.1, R10.1 (A), U1.6 (GND), U$2.P$5 (GND), U$2.P$11 (DB0), U$2.P$12 (DB1), U$2.P$13 (DB2), U$2.P$14 (DB3), U$2.P$15 (DB4), U$2.P$16 (DB5), U$2.P$17 (DB6), U$2.P$18 (DB7), U$2.P$19 (DB8), U$2.P$20 (DB9), U$2.P$21 (DB10), U$2.P$22 (DB11), U$2.P$23 (DB12), U$2.P$24 (DB13), U$2.P$25 (DB14), U$2.P$26 (DB15), U$2.P$27 (DB16), U$2.P$28 (DB17), U$2.P$48 (LEDK1), U$2.P$49 (LEDK2), U$2.P$50 (LEDK3), U$2.P$51 (LEDK4)
GPIO5: PI1.29 (GPIO5)
HEADPHONES: J1.RSH, J1.TSH, R3.1, U1.3 (HPHONE)
L1: BTN_L1.P$ACTIVE, PI1.13 (GPIO27/GEN2)
LED: LED1.A, R2.1
LEFT: BTN_LEFT.P$ACTIVE, PI1.37 (GPIO26)
unnamed: R1.1, U$2.P$47 (LEDA)
PWM: C2.2, PI1.12 (GPIO18)
R1: BTN_R1.P$ACTIVE, PI1.5 (GPIO3/SCL1)
RESET: PI1.22 (GEN/6GPIO25), U$2.P$10 (RESET)
RIGHT: BTN_RIGHT.P$ACTIVE, PI1.33 (GPIO13)
SCL: PI1.23 (GPIO11/SCLK), U$2.P$30 (RSX)
SDI: PI1.19 (GPIO10/MOSI), U$2.P$42 (SDI)
SELECT: BTN_SELECT.P$ACTIVE, PI1.15 (GPIO22/GEN3)
START: BTN_START.P$ACTIVE, PI1.10 (RXD0/GPIO15)
SWITCH_IN+: POWER1.OUT+, U$1.P
SWITCH_OUT+: C4.1, PI1.2 (5V0), PI1.4 (5V0), R2.2, R3.2, R10.5 (E), U1.1 (VDD), U$1.S
UP: BTN_UP.P$ACTIVE, PI1.35 (GPIO19)
VIN: C2.1, U1.2 (VIN)
VIN1: C1.-, J1.RING, J1.TIP, R4.2
VOUT1: C1.+, J2.1, U1.5 (VOUT1)
VOUT2: J2.2, U1.8 (VOUT2)
VUSB: J4.1 (VBUS), POWER1.IN+
X: BTN_X.P$ACTIVE, PI1.7 (GPIO4/GCKL)
Y: BTN_Y.P$ACTIVE, PI1.11 (GPIO17/GEN0)

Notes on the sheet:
D-PAD BUTTONS
FACE BUTTONS
FUNCTION BUTTONS
POWER
BATTERY
SWITCH
LED
DISPLAY
RASPBERRY PI
AUDIO
CREDITS
32teeth SuperAngryPixel Xi xi jia Jin

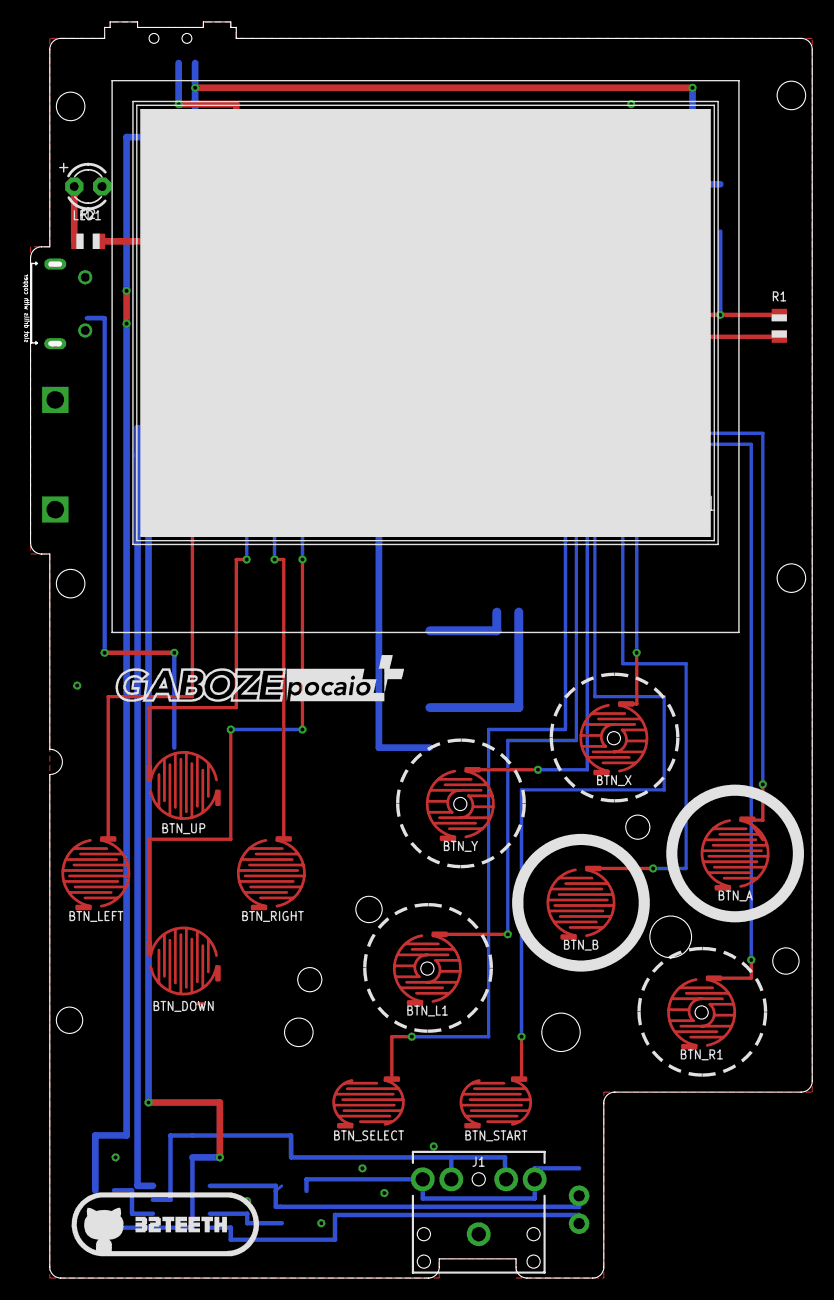
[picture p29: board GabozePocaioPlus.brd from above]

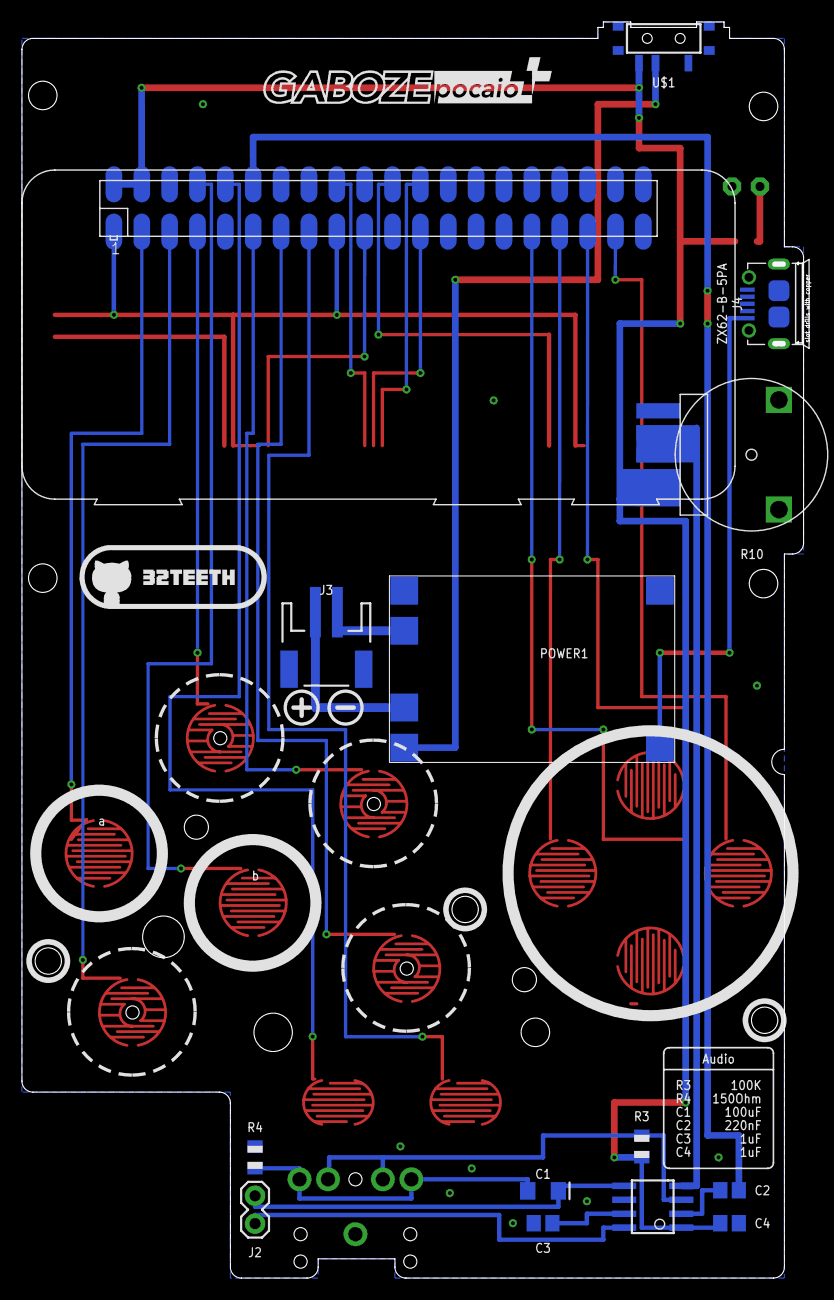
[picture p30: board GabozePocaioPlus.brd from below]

Board: 2 copper layers, 71.2 x 114.5 mm, 31 parts (14 on the bottom side), 34 nets.

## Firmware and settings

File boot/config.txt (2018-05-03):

# For more options and information see
# http://rpf.io/configtxt
# Some settings may impact device functionality. See link above for details

# uncomment if you get no picture on HDMI for a default "safe" mode
#hdmi_safe=1

# uncomment this if your display has a black border of unused pixels visible
# and your display can output without overscan
disable_overscan=0
overscan_scale=1

# uncomment the following to adjust overscan. Use positive numbers if console
# goes off screen, and negative if there is too much border
overscan_left=15
overscan_right=-30
overscan_top=-30
overscan_bottom=-30


# uncomment to force a console size. By default it will be display's size minus
# overscan.
framebuffer_width=320
framebuffer_height=240

# uncomment if hdmi display is not detected and composite is being output
#hdmi_force_hotplug=1

# uncomment to force a specific HDMI mode (this will force VGA)
hdmi_group=1
hdmi_mode=8

# uncomment to force a HDMI mode rather than DVI. This can make audio work in
# DMT (computer monitor) modes
#hdmi_drive=2

# uncomment to increase signal to HDMI, if you have interference, blanking, or
# no display
#config_hdmi_boost=4

# uncomment for composite PAL
#sdtv_mode=2

#uncomment to overclock the arm. 700 MHz is the default.
#arm_freq=800

# Uncomment some or all of these to enable the optional hardware interfaces
#dtparam=i2c_arm=on
#dtparam=i2s=on
dtparam=spi=on

# Uncomment this to enable the lirc-rpi module
#dtoverlay=lirc-rpi

# Additional overlays and parameters are documented /boot/overlays/README

# Enable audio (loads snd_bcm2835)
dtparam=audio=on
gpu_mem_256=128
gpu_mem_512=256
gpu_mem_1024=256
#overscan_scale=1

dtoverlay=pwm,pin=18,func=2

# Rotate screen for Gameboy Pocket Zero
lcd_rotate=2
initramfs initrd.img-4.9.35+

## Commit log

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2017-03-17 added no mcu version
    [GBZP-no-mcu.brd, GBZP-no-mcu.sch]
2017-03-31 new pinout to match GBZ project
    [GBZP.brd, GBZP.sch]
2017-04-03 Mon Apr 3 10:04:51 EDT 2017 - added new pin mapping
    [EIA3216.skp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]
2017-04-03 Mon Apr 3 10:13:43 EDT 2017 - added new pin mapping
    [GBZP-no-mcu.brd, GBZP-no-mcu.sch, GBZP.brd]
2017-04-03 Mon Apr 3 10:14:23 EDT 2017 - added new pin mapping
    [GBZP.skp]
2017-04-11 Added 3D models (stl files)
    [GBPZ-bottom.stl, GBPZ-top.stl, Gameboy.stl]
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2017-08-09 Wed Aug 9 10:25:52 EDT 2017 new version of GBZP
    [GBZP.GBL, GBZP.GBO, GBZP.GBP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]
2017-08-14 Mon Aug 14 17:07:33 EDT 2017 - Added Breakout to Silk Layer in PCB
    [GBZP.skp, GBZP~.skp]
2017-09-28 Thu 28 Sep 2017 18:31:30 EDT
    [GBPZ-bottom.stl, GBPZ-top.stl, GBZP.brd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]
2017-09-29 Fri Sep 29 08:38:18 EDT 2017 - cleaning schematics
    [GBZP.brd, GBZP.sch]
2017-09-29 Fri 29 Sep 2017 10:20:31 EDT
    [GBZP.brd, GBZP.sch, _old.brd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]
2017-09-29 Fri 29 Sep 2017 19:00:00 EDT
    [GBZP.brd, GBZP.sch]
2017-10-01 Sun Oct 1 16:53:47 EDT 2017
    [GBZP.sch]
2017-10-01 Sun Oct 1 17:41:23 EDT 2017
    [GBZP.brd]
2017-10-02 Sun Oct 1 21:02:41 EDT 2017
    [GBZP.brd, GBZP.sch]
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2017-10-03 Mon Oct 2 22:18:43 EDT 2017
    [GBZP.brd]
2017-10-03 Mon Oct 2 23:35:09 EDT 2017
    [GBZP.brd, GBZP.sch]
2017-10-06 Fri 6 Oct 2017 16:14:36 EDT
    [GBZP.GBL, GBZP.GBO, GBZP.GBP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]
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2017-10-31 Tue 31 Oct 2017 16:24:12 EDT
    [GBZP.sch]
2017-11-06 Mon 6 Nov 2017 08:50:14 EST
    [GBZP.brd, GBZP.sch]
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2017-11-29 Tue 28 Nov 2017 19:11:42 EST - ITS MACRO TIME
    [gameboy-macro.brd, gameboy-macro.sch]
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2018-01-29 fixed 2.4" LCD position
    [gameboy-pocket.GBL, gameboy-pocket.GBO, gameboy-pocket.GBP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]
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2018-02-28 Wed Feb 28 00:38:41 EST 2018 - added top silk
    [gameboy-pocket.brd]
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2018-03-10 Fri 9 Mar 2018 22:54:46 EST - initial commit for sharing
    [gameboy-pocket.brd, gameboy-pocket.sch]
2018-04-16 Mon 16 Apr 2018 10:01:08 EDT - Clean Up for Rebrand
    [03962A~.skp, 1X02.skp, 2x20.skp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]
2018-04-17 Tue 17 Apr 2018 16:29:39 EDT - Clean Up for Rebrand
    [gameboy-pocket.GBL, gameboy-pocket.GBO, gameboy-pocket.GBP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]
2018-04-17 Tue 17 Apr 2018 16:31:36 EDT - Clean Up for Rebrand
    [gameboy-pocket.csv]
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2018-04-24 Tue 24 Apr 2018 11:37:34 EDT - Final Product Gerbers Uploaded and Renamed
    [GabozePocaio.GBL, GabozePocaio.GBO, GabozePocaio.GBP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]
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2018-04-30 Mon 30 Apr 2018 06:26:32 EDT - rotate display
    [GabozePocaio.GBL, GabozePocaio.GBO, GabozePocaio.GBP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]
2018-05-02 Tue 1 May 2018 20:50:57 EDT - added overscan for 2.4 inch screen
    [config.txt]
2018-05-03 Thu 3 May 2018 12:15:34 EDT - Added Components in README
    [gameboy-pocket.csv]
2018-05-03 Thu 3 May 2018 12:43:31 EDT - Clean and Sync with Dev
    [03962A.skp, AUDIO-JACK.skp, C0805.skp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]
2018-05-15 Tue 15 May 2018 10:58:43 EDT - update BOM
    [GabozePociao.csv, gameboy-pocket.csv]
2018-05-15 Tue 15 May 2018 11:01:23 EDT - update gerbers
    [GabozePocaio.GBL, GabozePocaio.GBO, GabozePocaio.GBP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]
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2018-07-06 Fri 6 Jul 2018 16:18:57 EDT - added libraries
    [GabozePocaio.GBL, GabozePocaio.GBO, GabozePocaio.GBP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]
2018-07-06 Fri 6 Jul 2018 16:19:57 EDT - updated Layout
    [GabozePocaioLayout.brd, GabozePocaioLayout.sch]
2018-07-06 Fri 6 Jul 2018 16:31:20 EDT - updated Layout
    [GabozePocaio.GTS]
2018-07-06 Fri 6 Jul 2018 16:41:46 EDT - updated Layout
    [GabozePocaio.GTL, GabozePocaio.GTP, GabozePocaio.GTS]
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2018-07-09 Mon 9 Jul 2018 07:03:52 EDT - added DISCLAIMER.md for gerbers
    [GabozePocaio.GBL, GabozePocaio.GBO, GabozePocaio.GBP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]
2018-07-09 Mon 9 Jul 2018 07:06:11 EDT - updated layour eagle files
    [GabozePocaioLayout.brd, GabozePocaioLayout.sch]
2018-07-12 Wed 11 Jul 2018 21:18:07 EDT - updated layour eagle files
    [GabozePocaio.GBL, GabozePocaio.GBO, GabozePocaio.GBP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]
2018-07-12 Thu 12 Jul 2018 12:41:02 EDT - general cleanup
    [GabozePocaio.GBL, GabozePocaio.GBO, GabozePocaio.GBP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]
2018-07-13 Fri 13 Jul 2018 07:20:31 EDT - updated layout eagle files with new buttons
    [GabozePocaioLayout.brd, GabozePocaioLayout.sch]
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2018-08-09 Thu 9 Aug 2018 09:28:51 EDT - Released PCB (SCH/BRD/Gerbers/ZIP) for Official Release to Public
    [GabozePocaio.GBL, GabozePocaio.GBO, GabozePocaio.GBP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]
2018-08-09 Thu 9 Aug 2018 09:29:46 EDT - Released PCB (SCH/BRD/Gerbers/ZIP) for Official Release to Public
    [GabozePocaio.GBL, GabozePocaio.GBO, GabozePocaio.GBP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]
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2018-09-06 Thu 6 Sep 2018 12:15:06 EDT added gerbers for extension boards
    [GabozePocaio-Extension-Aux.GBL, GabozePocaio-Extension-Aux.GBO, GabozePocaio-Extension-Aux.GBP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]
2018-09-13 Thu 13 Sep 2018 10:30:32 EDT updated BOM
    [GabozePociaoPlus.csv]
2018-09-13 Thu 13 Sep 2018 10:31:57 EDT updated BOM
    [GabozePociao.csv]
2018-09-18 Tue 18 Sep 2018 17:13:24 EDT - added .stl file for 3d printing cartridge shell
    [cartridge.stl]
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2018-09-19 Wed 19 Sep 2018 13:57:21 EDT - added 2.6" upgrrade
    [GabozePocaioUpgrade.GBL, GabozePocaioUpgrade.GBO, GabozePocaioUpgrade.GBP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]
2018-09-19 Wed 19 Sep 2018 14:04:33 EDT - added 2.6" upgrade
    [GabozePocaio.GBL, GabozePocaio.GBO, GabozePocaio.GBP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]

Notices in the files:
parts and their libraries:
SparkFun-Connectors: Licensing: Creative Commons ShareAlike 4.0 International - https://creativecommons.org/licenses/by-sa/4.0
